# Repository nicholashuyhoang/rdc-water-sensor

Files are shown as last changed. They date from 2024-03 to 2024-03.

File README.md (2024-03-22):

# WaterSensor
Water sensor PCB design project.

Given: 5V Source
Want: 1'x 1' Water Sensor
Constraints: Vout to have a maximum of 3.3V for analog read in, Minimize current draw to be on the magnitude of 1mA

Use N23904 NPN transistor for low current and high robustness. Open schematic for reference.

Calculations
--------------------------------------------------------------------------------------------------------------------------
Assume forward active region:

If we want Vout to have a maximum of 3.3V and we want to minimize current draw to be on the magnitude of 1mA

R2 = 3.3V/1mA = 3.3k ohm 

Ie = 1mA

From testing 2N3904 (did not know the company that made the provided transistor): For Ic = 1mA @ 25 deg celsius, hfe or betaforward current gain is 300.

Ib = Ie/300 = 3.333micro A

We know that Ie = Ic+Ib so Ic = 299/300Ie. They are roughly equal. From testing 2N3904: For Ic = 1mA @ 25 deg celsius, Vbe = 0.67 V.

Vs-(R2*Ib)-Vbe <= Vout ----> 5V-(R2*3.333micro A)-0.67V <= 3.3V

R2 >= 309.03k ohm ---> R2 = 330k ohm

Discussion
--------------------------------------------------------------------------------------------------------------------------
The water sensor is designed with maximum sensitivity in mind. Per competition requirements: Need to detect a 20mL hit but points are awarded for detection of smaller mL hits.

Sensitivity can be decreased by increasing the spacing between the power lines and the copper fill connected to the base of the transistor. 
Additionally, every other power line can be removed to decrease sensitivity.

One potential issue with such a high level of sensitivity is that there is the possibility of a near hit miss balloon that is able to splatter up and over the board onto the sensor.
A mitigation technique for this issue is to erect walls on the border of the marker to prevent ground splash onto the sensor.

Another potential issue is the usage of deionized water. This design works by causing a "short" between two terminals.
A mitigiation technique for this issue is to place a layer of fine grain salt on the board. Salt itself is not conducting. However, it will provide conductivity when placed inside a medium.

Testing w/o AruCo marker, Vout readings: 1 drop - 2.75V, 2 drop - 2.9V, 3 drop - 2.94V, 4 drop - 2.96, 5 drop - 3V, 6 drop - 3V, 7 drop - 3.03V, 8 drop - 3.06V, 9 drop - 3.07V, 10 drop - 3.08V, 11 drop - 3.09V,  12 drop - 3.11V, Saturated - 3.3V

1mL is roughly 25 drops

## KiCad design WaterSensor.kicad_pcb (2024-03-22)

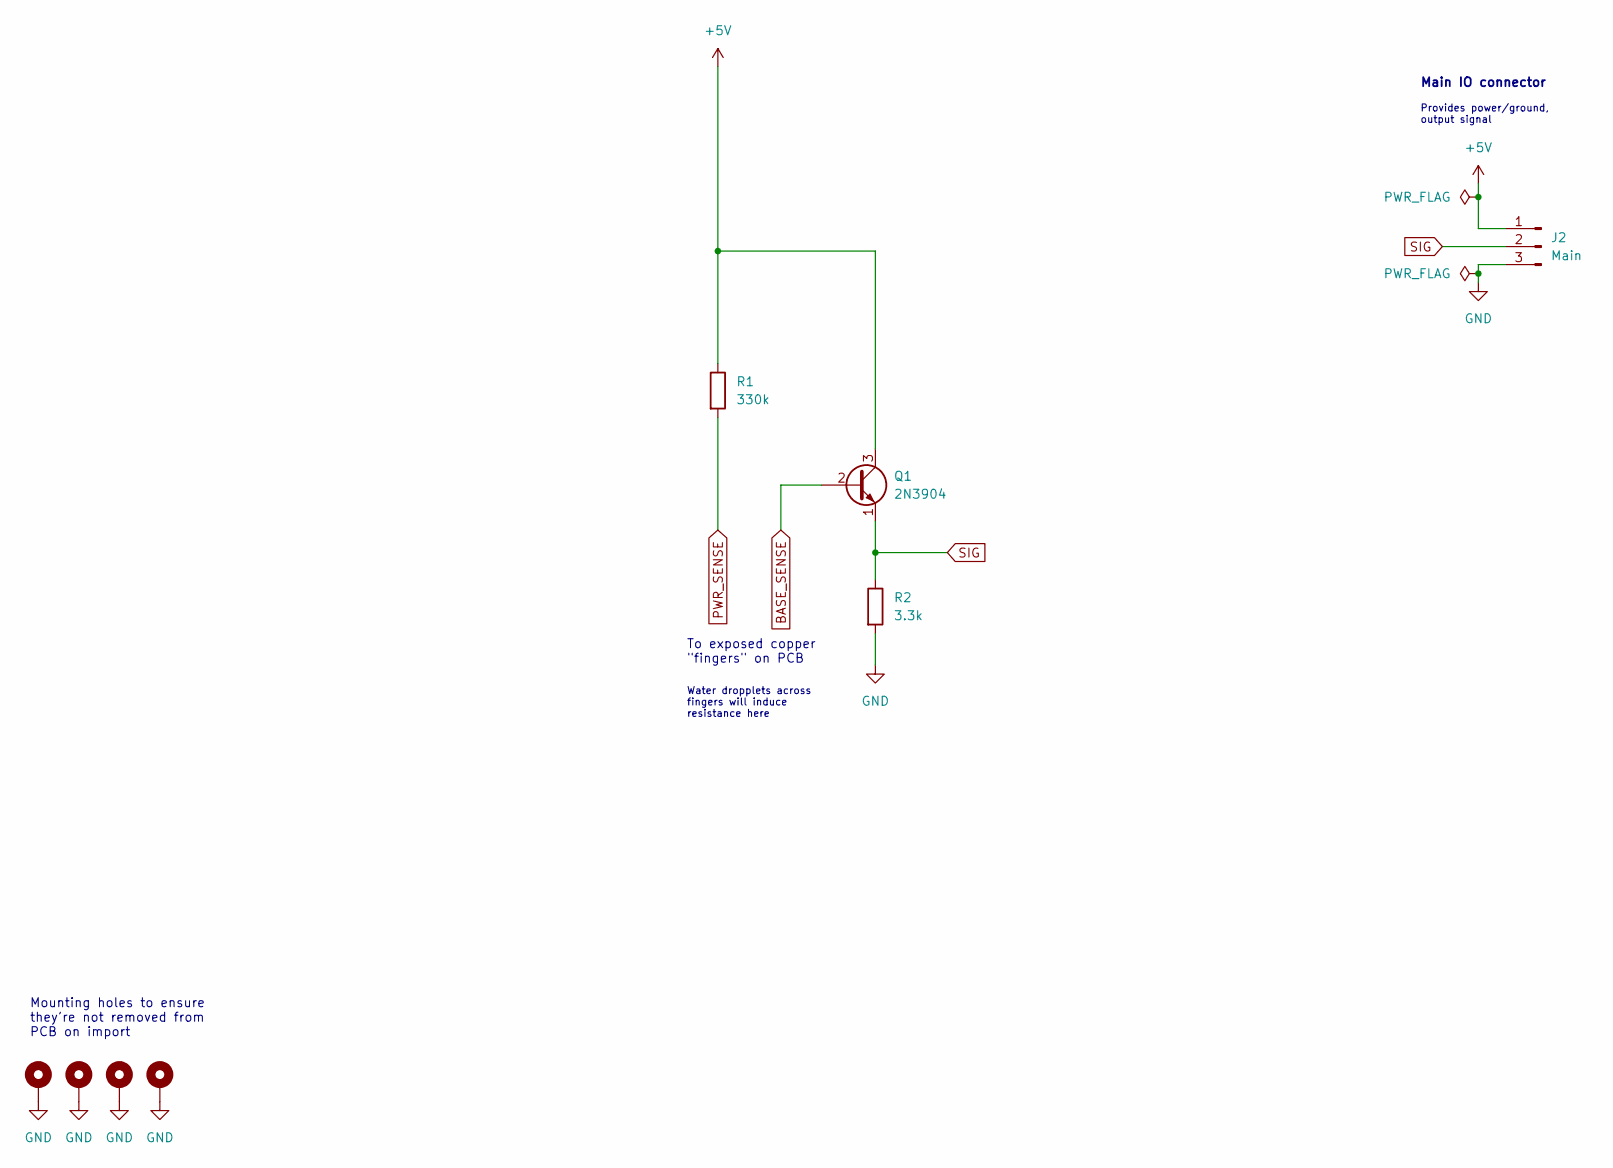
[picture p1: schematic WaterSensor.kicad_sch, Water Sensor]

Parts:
H1, H2, H3, H4: MountingHole_Pad; MountingHole_2.5mm_Pad_Via
J2: Main; PinHeader_1x03_P2.54mm_Vertical
Q1: 2N3904; TO-92_Inline
R1: 330k; R_Axial_DIN0204_L3.6mm_D1.6mm_P1.90mm_Vertical
R2: 3.3k; R_Axial_DIN0204_L3.6mm_D1.6mm_P1.90mm_Vertical

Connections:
+5V: J2.1, Q1.3 (C), R1.1
BASE_SENSE: Q1.2 (B)
GND: H1.1, H2.1, H3.1, H4.1, J2.3, R2.2
PWR_SENSE: R1.2
SIG: J2.2, Q1.1 (E), R2.1

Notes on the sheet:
Mounting holes to ensure they're not removed from PCB on import
Water dropplets across fingers will induce resistance here
Provides power/ground, output signal
Main IO connector
To exposed copper "fingers" on PCB

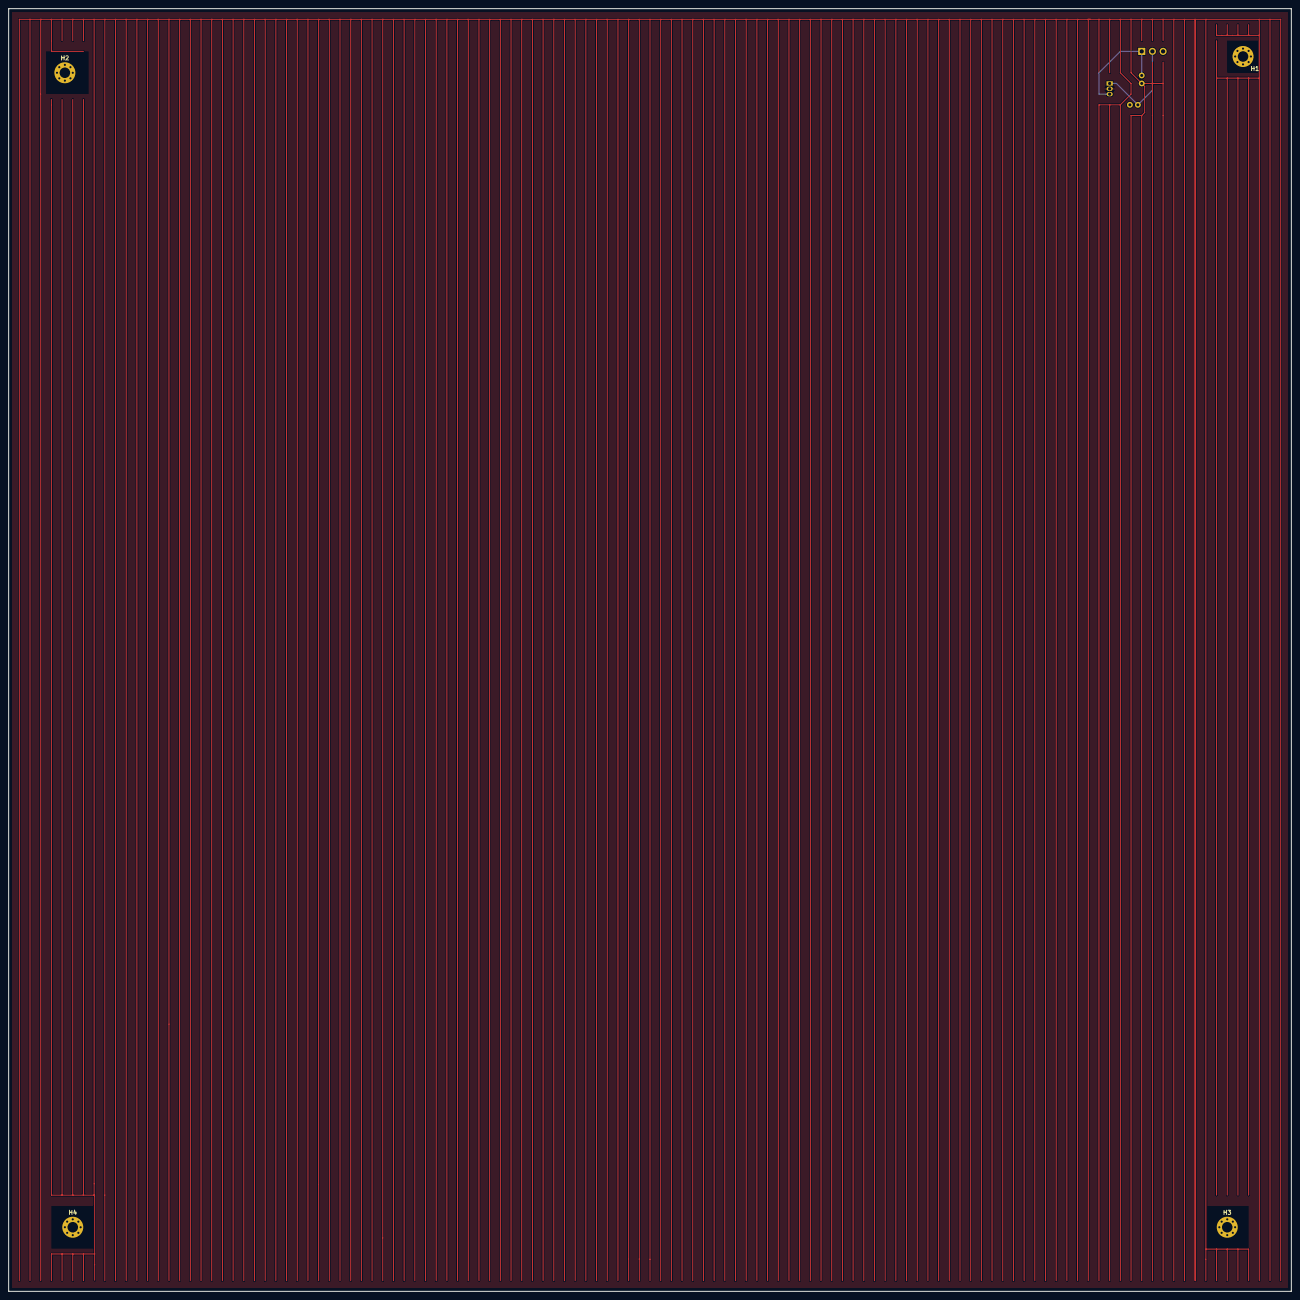
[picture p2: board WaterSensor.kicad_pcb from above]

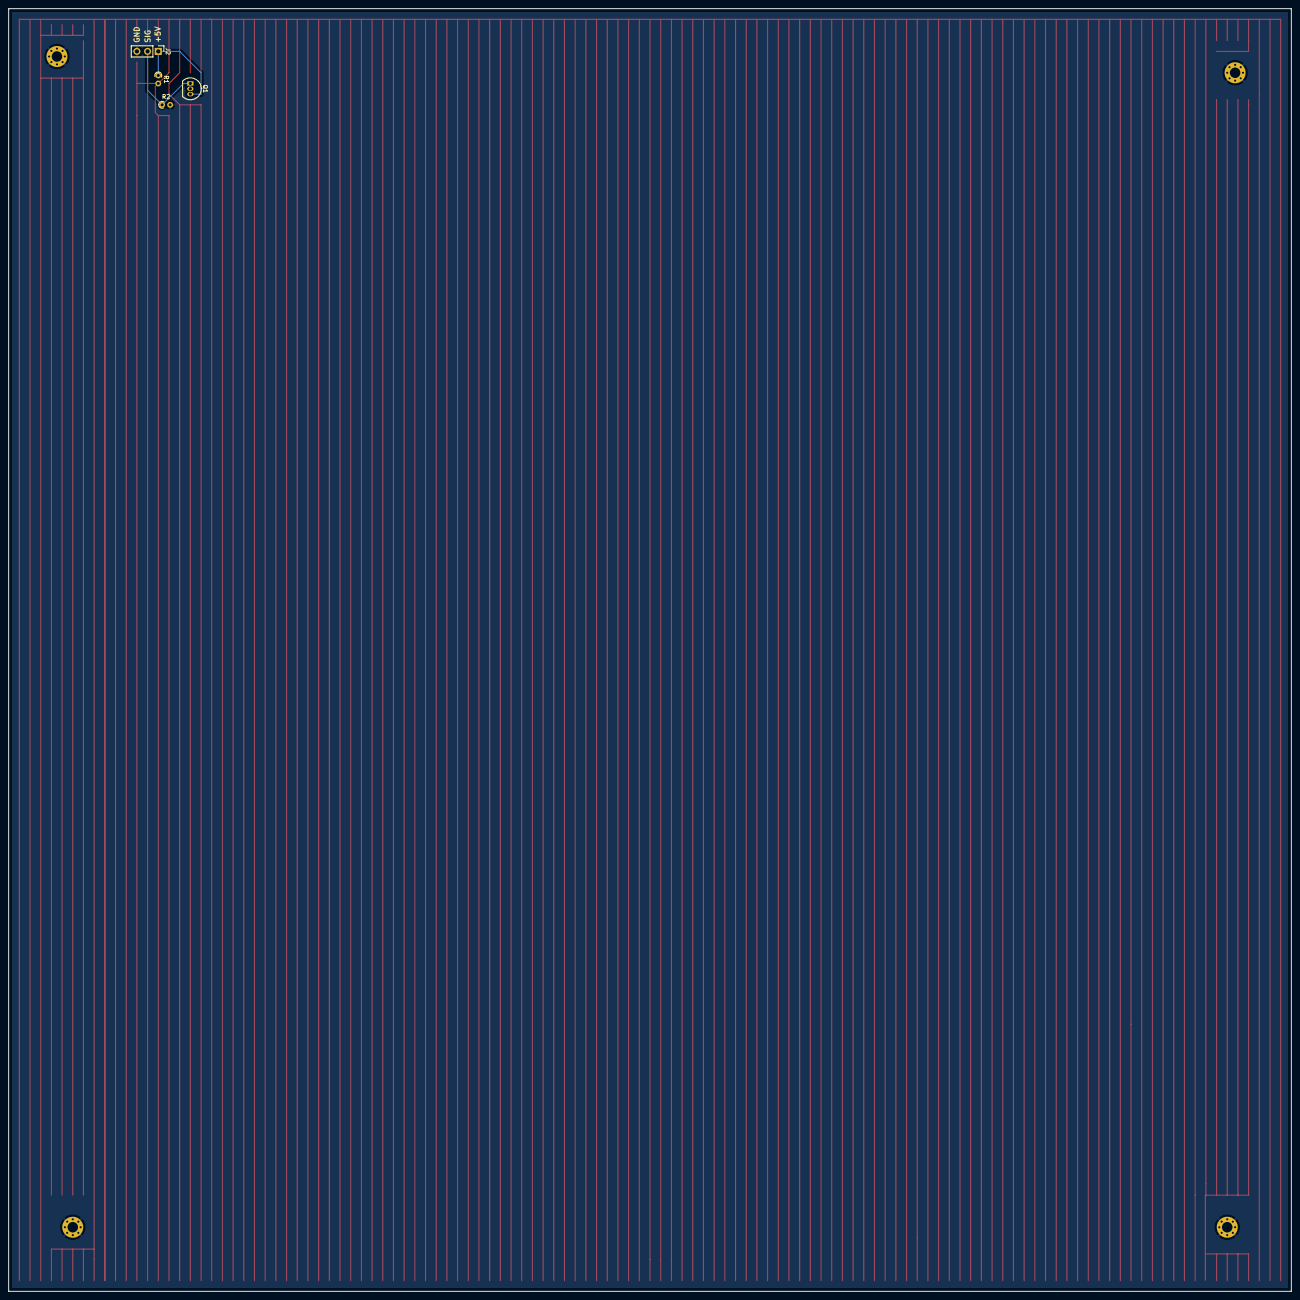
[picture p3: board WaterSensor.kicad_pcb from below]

Board: 2 copper layers, 304.8 x 304.8 mm, 8 parts (4 on the bottom side), 3 nets.

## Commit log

2024-02-23 Initial import
    [WaterSensor.kicad_pcb, WaterSensor.kicad_sch]
2024-02-23 General cleanup of schematic and PCB
    [WaterSensor.kicad_pcb, WaterSensor.kicad_sch]
2024-02-24 Change spiral design to finger design
    [WaterSensor.kicad_pcb]
2024-02-25 Removed extra back-side ground plane, added silk screen, added front side mask to expose copper
    [WaterSensor.kicad_pcb]
2024-02-26 Move H1 text outside of copper region
    [WaterSensor.kicad_pcb]
2024-02-26 Update footprints to Kicad 8.0, remove track violation from keepout areas
    [WaterSensor.kicad_pcb]
2024-03-20 Add water sensor SPICE schematic
2024-03-20 Add pulldown resistor and update resistor values to bias a 3.3V output
    [WaterSensor.kicad_pcb, WaterSensor.kicad_sch]
2024-03-22 Reverse changes as pulldown resistor is not needed
    [WaterSensor-B_Cu.gbr, WaterSensor-B_Mask.gbr, WaterSensor-B_Paste.gbr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]
2024-03-22 Update resistor values based on calculations in README
    [WaterSensor-B_Cu.gbr, WaterSensor-B_Mask.gbr, WaterSensor-B_Paste.gbr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]
